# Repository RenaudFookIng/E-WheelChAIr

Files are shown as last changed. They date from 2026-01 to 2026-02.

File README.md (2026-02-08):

# E-WheelChAIr
**Smart Embedded System for Electric Wheelchairs**




---

## Description
E-WheelChAIr is an open-source project designed to enhance autonomy and accessibility for electric wheelchairs. It integrates:
- A **ROS2-based architecture** for real-time control and sensor fusion.
- **3D-printed mechanical parts** (sensor mounts, joystick adapters).
- **Modular design** for easy customization and collaboration with partners like Sorbonne University.

---

## 📸 Visual Overview

### Wheelchair Views

<div align="center">
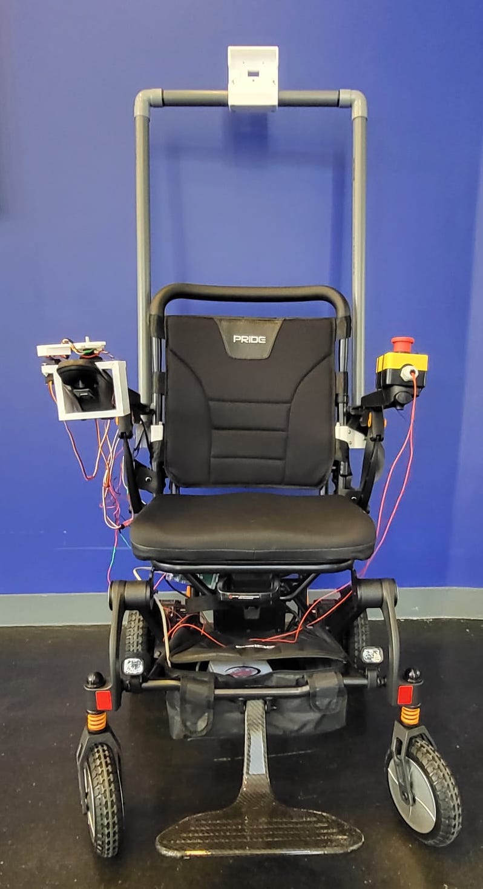
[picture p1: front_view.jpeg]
Front View
  
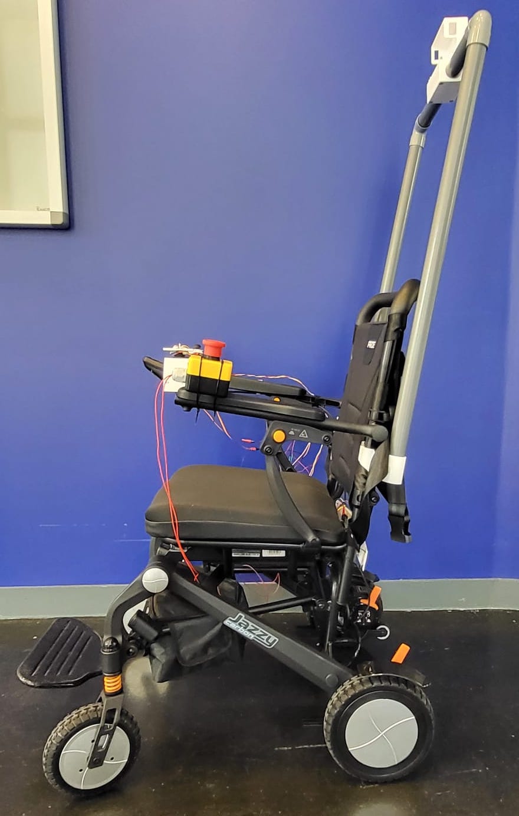
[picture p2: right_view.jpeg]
Right View
  
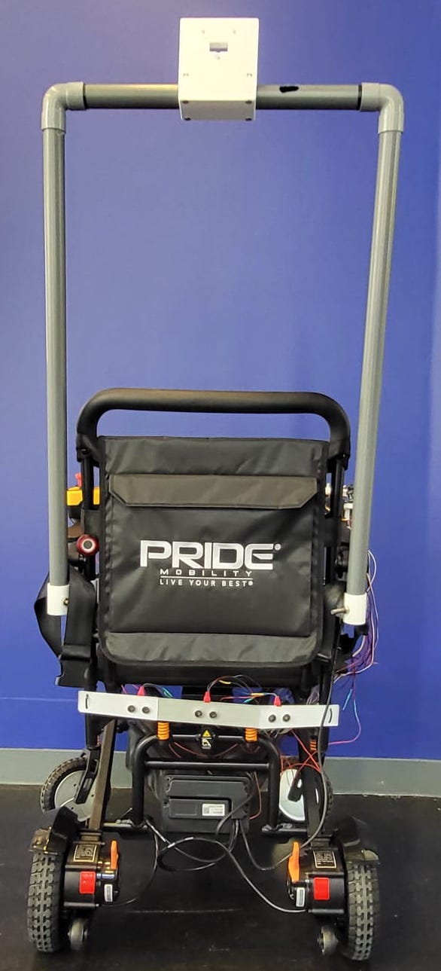
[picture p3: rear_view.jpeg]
Rear View
  
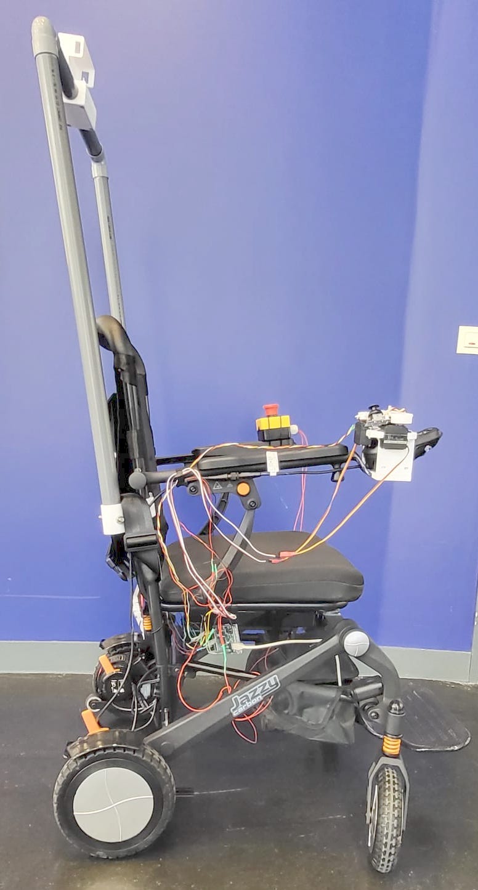
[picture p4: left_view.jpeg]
Left View
  
</div>

---

## Project Structure

**Note:** All ROS launch files are centralized in the `e_wheelchair_launch` package for easier management.

```
E-WheelChAIr/
├── hardware
│   ├── 3d_models
│   │   ├── BackRest_Fixation/
│   │   │   ├── Fixation_BackRest.iges
│   │   │   ├── Fixation_backrest_part1.stl
│   │   │   └── Fixation_backrest_part2.stl
│   │   ├── Camera_Module/
│   │   │   ├── Camera_module.iges
│   │   │   ├── Fixation_camera.stl
│   │   │   ├── Fixation_camera_up.stl
│   │   │   └── Support_camera.stl
│   │   ├── ServoControl_Joystick/
│   │   │   ├── BasePart.stl
│   │   │   ├── FourchetteAxeX.stl
│   │   │   ├── FourchetteAxeY.stl
│   │   │   ├── Servo_controller_Joystick.iges
│   │   │   ├── Support_servo_joystick.stl
│   │   │   └── Visuel_Joystick_servomoteur_support.png
│   │   └── Ultrasonic_Module/
│   │
│   ├── arduino/
│   │   ├── ewheelchair_controller/
│   │   │   ├── ewheelchair_controller.ino
│   │   │   └── lecture_arduino.py
│   │   ├── ARDUINO_GUIDE.md
│   │   ├── FILES_SUMMARY.md
│   │   ├── README.md
│   │   └── test_arduino.py
│   │
│   ├── Image_processing/
│   │   ├── cmd.txt
│   │   ├── ROS.txt
│   │   ├── vision_config_gpu.py
│   │   ├── vision_config_mac.py
│   │   ├── vision_system_gpu.py
│   │   ├── vision_system_mac.py
│   │   ├── yolo11n.pt
│   │   └── yolov8n.pt
│   │
│   └── Right_View.jpeg
│
├── resources
│   ├── docs
│   └── utils
|
├── src
|   ├── arduino_bridge/
|   │   ├── arduino_bridge
|   │   │   ├── __init__.py
|   │   │   └── arduino_bridge_node.py
|   │   ├── resource
|   │   │   └── arduino_bridge
|   │   ├── test
|   │   │   ├── test_copyright.py
|   │   │   ├── test_flake8.py
|   │   │   └── test_pep257.py
|   │   ├── package.xml
|   │   ├── setup.cfg
|   │   └── setup.py
|   ├── custom_msgs/
|   │   ├── msg/
|   │   │   ├── EmergencyData.msg
|   │   │   ├── Joystick.msg
|   │   │   ├── ObstacleDetection.msg
|   │   │   ├── ServoCommand.msg
|   │   │   ├── UltrasonicArray.msg
|   │   │   ├── VisionObstacle.msg
|   │   │   └── WyesIntent.msg
|   │   ├── CMakeLists.txt
|   │   ├── package.xml
|   │   └── setup.py
|   ├── e_wheelchair_launch/
|   │   ├── e_wheelchair_launch
|   │   │   ├── __init__.py
|   │   │   └── launch/
|   │   ├── resource/
|   │   │   └── e_wheelchair_launch
|   │   ├── package.xml
|   │   ├── setup.cfg
|   │   └── setup.py
|   ├── master_node/
|   │   ├── config/
|   │   │   ├── master_config.yaml
|   │   │   └── servo_config.yaml
|   │   ├── master_node/
|   │   │   ├── __init__.py
|   │   │   ├── master_node.py
|   │   │   └── master_node_bis.py
|   │   ├── package.xml
|   │   ├── setup.cfg
|   │   └── setup.py
|   ├── pc_vision_bridge/
|   │   ├── pc_vision_bridge
|   │   │   ├── __init__.py
|   │   │   └── pc_vision_bridge_node.py
|   │   ├── resource
|   │   │   └── pc_vision_bridge
|   │   ├── test
|   │   │   ├── test_copyright.py
|   │   │   ├── test_flake8.py
|   │   │   └── test_pep257.py
|   │   ├── package.xml
|   │   ├── setup.cfg
|   │   └── setup.py
|   └── wyes_teleop/
|       ├── resource
|       │   └── wyes_teleop
|       ├── test
|       │   ├── test_copyright.py
|       │   ├── test_flake8.py
|       │   └── test_pep257.py
|       ├── wyes_teleop
|       │   ├── __init__.py
|       │   └── wyes_teleop_node.py
|       ├── package.xml
|       ├── setup.cfg
|       └── setup.py
|
├── .gitignore
├── CABLAGE_SCHEMA.md
├── E-WheelChAIr.mp4
├── LICENSE
├── parametrage_raspberry_hotspot.txt
├── README.md
├── TESTING_GUIDE.md
└── yolov8n.pt
```

---

## Prerequisites

### Hardware
- Electric wheelchair with servo-controlled joystick (using Miuzei MZ996 servos).
- Sensors: Intel Realsense (depth camera), HC-SR04 (ultrasonic), Arduino (I/O interface).
- Joystick or alternative control input device.

### Software
- ROS2 Jazzy.
- colcon (build tool for ROS2).
- OnShape (for 3D modeling).
- Git LFS (for versioning large 3D files).
- Python 3.9+ with pyserial and pyyaml packages.

---

## Installation and Setup On your computer

### 1. Clone the Repository
```bash
git clone https://github.com/RenaudFookIng/E-WheelChAIr.git
cd E-WheelChAIr
```

### 2. Build the ROS Workspace
```bash
colcon build --symlink-install
source install/setup.bash
```

### 3. Launch the System
```bash
ros2 launch e_wheelchair_launch ewheelchair_all.launch.py
```
## Installation and Setup On your Raspberry PI

### 1. Cloner le dépôt en mode "sparse-checkout"
```bash
git clone --filter=blob:none --no-checkout https://github.com/RenaudFookIng/E-WheelChAIr.git
cd E-WheelChAIr
```
### 2. Active le mode sparse-checkout et exclut le dossier 'hardware'
```bash
git sparse-checkout init --cone
git sparse-checkout set --no-cone /* !/hardware/
```
### 3. Extrait les fichiers (sauf 'hardware')
```bash
git checkout main
```

## Build the ROS Workspace
```bash
colcon build --symlink-install
source install/setup.bash
```

---

## ROS Launch Files Centralization

All ROS launch files have been centralized in the `e_wheelchair_launch` package to provide:

- **Simplified Management**: Single location for all launch configurations
- **Easier Maintenance**: No duplication across packages
- **Consistent Structure**: Uniform approach to system launching
- **Better Organization**: Clear separation between nodes and launch configurations

### Available Launch Files

| Launch File | Description | Components Launched |
|---|---|---|
| `ewheelchair_all.launch.py` | Complete system with all sensors and processing | 6 nodes |
| `ewheelchair_joystick_servo.launch.py` | Control servo with joystick and Ultrasonic sensor | 2 node |
| `ewheelchair_arduino_vision.launch.py` | Control servo with joystick and Ultrasonic sensor and Wide-angle camera processing | 3 node |
| `ewheelchair_wyes_teleop.launch.py` | Control servo with joystick, Ultrasonic sensor and Wyes Glasses | 3 node |

## ROS Packages

| Package | Description |
|---|---|
| `arduino_bridge` | Receives data from Arduino sensors |
| `custom_msgs` | Custom ROS message definitions |
| `e_wheelchair_launch`  | Launch files for the complete system |
| `master_node` | Main control node for servo-controlled joystick |
| `pc_vision_bridge` | Bridge between PC vision system and ROS |
| `wyes_teleop` | Keyboard-based teleoperation interface |

---
Pour se connecter au Hotspot WiFi :
- Nom du Hotspot : E-Wheelchair
- Mot de passe : REDACTED_WIFI_PASSWORD

Pour se connecter à la plateforme :
Nom de la plateforme : ewheelchair2
```bash
ssh ewheelchair2@192.168.4.1
```
mdp : REDACTED_SSH_PASSWORD

---

## 3D Models
- **Location**: [`3d_models/`](3d_models/)
- **Formats**: STL and STEP files for 3D printing and simulation.
- **Tools**: Designed in OnShape.
- **Note**: Use `git lfs pull` after cloning to retrieve 3D files.

---

## Recent Changes

### Version 0.2.0 (Current)
- **Major Architecture Change**: Replaced Sabertooth motor controller with Miuzei MZ996 servo-based joystick control
- **New Package**: `arduino_bridge` for Arduino-based servo management
- **Updated**: `master_node` now publishes joystick commands instead of motor commands
- **Updated**: `visualization` package removed motor speed plotting
- **Improved**: Safety features with neutral position on emergency stop

### Version 0.1.0
- Initial release with Sabertooth motor controller
- Basic sensor integration (ultrasonic, camera)
- ROS2 Jazzy compatibility

## Collaboration
- **University of Milan**: Partner for accessibility validation.
- **Contributions**: Pull requests and issues are welcome!
- **License**: Apache 2.0 (see [LICENSE](LICENSE)).

---

## Contact
- **Maintainer**: Renaud JANET ([@RenaudFookIng](https://github.com/RenaudFookIng))
- **Support**: Open an [issue](https://github.com/RenaudFookIng/E-WheelChAIr/issues) for questions or suggestions.

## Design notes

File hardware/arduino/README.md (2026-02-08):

# E-WheelChAIr Arduino Controller

This directory contains the Arduino firmware for the E-WheelChAIr project.

## 📁 Files

- `ewheelchair_controller/ewheelchair_controller.ino` - Main Arduino sketch for Arduino Mega 2560
- `test_arduino.py` - Python test script for verifying Arduino functionality

## 🎯 Hardware Requirements

- **Arduino Mega 2560** (required for sufficient pins)
- **Joystick PS2** - Analog joystick for user input
- **2x MZ996R Servos** - For wheelchair joystick manipulation
- **4x HC-SR04 Ultrasonic Sensors** - For obstacle detection
- **6V Power Supply** - For servos (NOT from Arduino!)

## 🔌 Pin Configuration

### Analog Inputs
- **A0**: Joystick X-axis
- **A1**: Joystick Y-axis

### Digital Outputs
- **D9**: Servo Y (Vertical - Forward/Backward)
- **D10**: Servo X (Horizontal - Left/Right)
- **30**: Ultrasonic 1 Trigger (Rear Right sensor)
- **31**: Ultrasonic 1 Echo (Rear Right sensor)
- **32**: Ultrasonic 2 Trigger (Rear Central sensor)
- **33**: Ultrasonic 2 Echo (Rear Central sensor)
- **34**: Ultrasonic 3 Trigger (Rear Left sensor)
- **35**: Ultrasonic 3 Echo (Rear Left sensor)

### Power
- **5V**: Power for ultrasonic sensors and joystick
- **GND**: Common ground for all components

## 📦 Installation

### 1. Install Arduino IDE

```bash
# For Ubuntu/Debian
sudo apt install arduino

# Or download from https://www.arduino.cc/en/software
```

### 2. Install Required Libraries

The sketch uses the standard `Servo.h` library which comes with Arduino IDE.

### 3. Upload the Code

1. Open `ewheelchair_controller/ewheelchair_controller.ino` in Arduino IDE
2. Select board: **Arduino Mega 2560**
3. Select port: Check with `ls /dev/ttyACM*` on Linux or COM port on Windows
4. Click **Upload** (→)

## 🚀 Usage

### Serial Communication Protocol

The Arduino communicates at **115200 baud** using the following protocol:

#### Commands (ROS2 → Arduino)

- **`SERVO,X,Y`**: Set servo positions
  - `X`: X-axis angle (77-107°, neutral=92°)
  - `Y`: Y-axis angle (70-100°, neutral=85°)
  - Example: `SERVO,90,85` (neutral position)

- **`NEUTRAL`**: Return servos to neutral position
  - Response: `NEUTRAL_OK`

- **`STATUS`**: Request current status
  - Response: `STATUS,X,Y,neutralX,neutralY,amplitude`

#### Data (Arduino → ROS2)

- **`JOYSTICK,X,Y`**: Joystick position data
  - `X`: X-axis angle (0-180°)
  - `Y`: Y-axis angle (0-180°)
  - Sent every 50ms (20Hz)

- **`ULTRASONIC,d1,d2,d3,d4`**: Ultrasonic sensor distances
  - `d1`: Front sensor distance (meters)
  - `d2`: Rear sensor distance (meters)
  - `d3`: Left sensor distance (meters)
  - `d4`: Right sensor distance (meters)
  - Sent every 50ms (20Hz)

- **`SERVO_OK,X,Y`**: Confirmation of servo movement
  - `X`: Actual X position set
  - `Y`: Actual Y position set

- **`ERROR,message`**: Error messages

## ⚙️ Configuration

### Servo Parameters

Edit these values in the sketch if needed:

```cpp
int neutralX = 92;    // Neutral position for X servo
int neutralY = 85;    // Neutral position for Y servo
int amplitude = 15;   // ±15° amplitude limit
```

### Safety Features

- **Timeout**: Servos automatically return to neutral after 1 second without commands
- **Amplitude Limit**: Strict ±15° limit to prevent over-extension
- **Distance Clamping**: Ultrasonic readings constrained to 2cm-4m range

## 🧪 Testing

### Run the Test Script

```bash
python3 test_arduino.py
```

### Manual Testing

1. **Joystick Test**: Move joystick and check serial output
2. **Servo Test**: Send `SERVO,92,85` command
3. **Ultrasonic Test**: Place hand in front of sensors
4. **Safety Test**: Disconnect serial and verify timeout

## 🔄 ROS2 Integration

The Arduino connects to the ROS2 system via:

```
Arduino Mega (USB) → Raspberry Pi (/dev/ttyACM0)
```

The ROS2 `arduino_bridge_node` sends commands and receives sensor data.

## ⚠️ Safety Instructions

1. **Always test servos before connecting to wheelchair**
2. **Use external 6V power for servos** (NOT from Arduino)
3. **Ensure common ground between all components**
4. **Keep emergency stop accessible**
5. **Verify ±15° amplitude limits before use**

## 📊 Troubleshooting

### Common Issues

**Problem**: Servos don't move
- Check 8V power connection
- Verify GND is common
- Test with simple Arduino servo example

**Problem**: Ultrasonic always shows 4.0m
- Check Trig/Echo wiring
- Verify 5V power connection
- Test with hand at 20cm distance

**Problem**: No serial communication
- Check USB cable connection
- Verify correct port selection
- Ensure baud rate is 115200
- Close Arduino Serial Monitor before running ROS2

**Problem**: Joystick not responding
- Check A0/A1 connections
- Verify 5V power to joystick
- Test with Arduino analog read example

## 📚 References

- [Arduino Servo Library](https://www.arduino.cc/en/Reference/Servo)
- [HC-SR04 Ultrasonic Sensor](https://www.electronicwings.com/sensors-modules/hc-sr04-ultrasonic-sensor)
- [PS2 Joystick Guide](https://www.instructables.com/How-to-Use-a-Joystick-With-Arduino/)

## 🎓 Notes

- The Y-axis neutral position is **85°** (not 90°) to match wheelchair mechanics
- The X-axis neutral position is **92°** (not 90°) to match wheelchair mechanics
- Servo amplitude is **strictly limited to ±15°** for safety
- All ultrasonic sensors are read sequentially to avoid interference
- Serial communication uses newline (`\n`) as command terminator

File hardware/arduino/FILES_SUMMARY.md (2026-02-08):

# 📁 E-WheelChAIr Arduino Files Summary

## 📂 Directory Structure

```
hardware/arduino/
├── ewheelchair_controller/
│   └── ewheelchair_controller.ino          # Main Arduino sketch (fully commented)
├── test_arduino.py                          # Python test script
├── README.md                                # Basic documentation
├── ARDUINO_GUIDE.md                         # Complete technical guide
├── FILES_SUMMARY.md                         # This file
└── (other documentation files)
```

## 📄 File Descriptions

### 1. `ewheelchair_controller/ewheelchair_controller.ino`
**Purpose**: Main Arduino sketch for E-WheelChAIr hardware control (fully documented)
**Size**: 11KB
**Language**: C++ (Arduino)
**Target**: Arduino Mega 2560

**Key Features:**
- Controls 2 servos with ±15° safety limits
- Reads PS2 joystick input
- Manages 3 ultrasonic sensors
- Serial communication at 115200 baud
- Safety timeout (1 second)
- Emergency stop function
- **Fully documented with line-by-line comments**

**Functions:**
- `setup()` - Initialization
- `loop()` - Main control loop
- `processSerialCommand()` - Command processing
- `sendJoystickData()` - Joystick data transmission
- `sendUltrasonicData()` - Ultrasonic data transmission
- `readUltrasonicDistance()` - Single sensor reading
- `moveToNeutral()` - Safety function
- `emergencyStop()` - Emergency function

**Documentation Includes:**
- Hardware requirements
- Pin definitions with explanations
- Servo configuration details
- Serial protocol specification
- Safety feature descriptions
- Testing procedures

### 3. `test_arduino.py`
**Purpose**: Python script for testing Arduino functionality
**Size**: 4KB
**Language**: Python 3
**Dependencies**: pyserial

**Key Features:**
- Automatic Arduino port detection
- Comprehensive test suite
- Serial communication validation
- Error handling and reporting
- Cross-platform support (Windows/Linux/macOS)

**Tests Performed:**
1. Port detection and connection
2. STATUS command validation
3. NEUTRAL command testing
4. SERVO command execution
5. Sensor data verification
6. Error response handling

**Usage:**
```bash
python3 test_arduino.py
```

### 4. `README.md`
**Purpose**: Basic documentation and quick start guide
**Size**: 5.4KB
**Format**: Markdown

**Sections:**
- Files overview
- Hardware requirements
- Pin configuration table
- Installation instructions
- Usage guide
- Serial protocol specification
- Safety instructions
- Troubleshooting guide
- References and links

**Key Information:**
- Hardware requirements list
- Pin mapping diagram
- Arduino IDE setup
- Upload instructions
- Serial protocol examples
- Common issues and solutions

### 5. `ARDUINO_GUIDE.md`
**Purpose**: Complete technical reference and user guide
**Size**: 11.8KB
**Format**: Markdown

**Sections:**
- Overview and system architecture
- Hardware components specification
- Detailed pin mapping
- Servo configuration guide
- Serial communication protocol
- Safety features explanation
- Data flow diagrams
- Testing procedures
- Wiring checklist
- Power requirements
- Troubleshooting guide
- Key concepts and theory
- Reference specifications
- Maintenance tips
- Glossary of terms
- Quick reference guide
- ROS2 integration
- Performance metrics
- Best practices

**Key Information:**
- Why Arduino Mega is required
- X-axis neutral position explanation (85°)
- Complete safety feature documentation
- Step-by-step testing procedures
- Power budget calculations
- Component specifications
- Integration with ROS2 nodes
- Maintenance schedule

## 📊 File Statistics

| File | Size | Lines | Language | Purpose |
|---|---|---|---|---|
| `ewheelchair_controller.ino` | 11KB | 420 | C++ | Main sketch (fully documented) |
| `test_arduino.py` | 4KB | 150 | Python | Test script |
| `README.md` | 5.4KB | 200 | Markdown | Quick start |
| `ARDUINO_GUIDE.md` | 11.8KB | 450 | Markdown | Complete guide |
| `FILES_SUMMARY.md` | 2KB | 80 | Markdown | This summary |

**Total**: ~40KB, ~1,500 lines of code and documentation

## 🔧 Development Tools

### Required Software
- **Arduino IDE** 1.8+ or 2.0+
- **Python** 3.6+
- **pyserial** library
- **Git** for version control

### Installation Commands
```bash
# Install Arduino IDE (Ubuntu/Debian)
sudo apt install arduino

# Install Python dependencies
pip3 install pyserial

# Clone repository
git clone https://github.com/your-repo/E-WheelChAIr.git
```

## 🚀 Getting Started

### 1. Upload Arduino Sketch
```bash
# Open Arduino IDE
arduino

# Select board: Arduino Mega 2560
# Select port: /dev/ttyACM0 or COMx
# Open ewheelchair_controller.ino
# Click Upload (→)
```

### 2. Run Test Script
```bash
python3 test_arduino.py
```

### 3. Connect to ROS2
```bash
# The Arduino will automatically connect to ROS2 via
# /dev/ttyACM1 at 115200 baud
```

## 📚 Documentation Hierarchy

```
Quick Start → README.md
            ↓
Detailed Guide → ARDUINO_GUIDE.md
            ↓
Code Reference → Commented sketch
            ↓
Testing → test_arduino.py
```

## 🎯 Key Features Summary

### Safety
- ±15° amplitude limiting
- 1-second timeout protection
- Emergency stop function
- Distance clamping (2cm-4m)

### Performance
- 20Hz update rate
- Low latency (<20ms)
- Efficient resource usage
- Reliable communication

### Documentation
- Complete pin mapping
- Detailed explanations
- Troubleshooting guides
- Best practices

### Testing
- Automatic port detection
- Comprehensive test suite
- Error handling
- Validation procedures

## 🔄 Version Control

### Git Repository Structure
```
hardware/arduino/
├── ewheelchair_controller/
│   └── ewheelchair_controller.ino
├── test_arduino.py
├── README.md
├── ARDUINO_GUIDE.md
└── FILES_SUMMARY.md
```

### Commit Message Template
```
[ARDUINO] Add complete hardware controller

- Main Arduino sketch for Mega 2560
- Fully documented version for understanding
- Python test script with automatic detection
- Comprehensive README and guide
- Safety features and testing procedures

Fixes #issue_number
```

## 📖 Usage Recommendations

### For Developers
1. Start with `README.md` for quick setup
2. Use the fully documented sketch for code understanding
3. Run test script for validation
4. Refer to `ARDUINO_GUIDE.md` for troubleshooting

### For Users
1. Upload main sketch to Arduino
2. Follow wiring diagram in `CABLAGE_SCHEMA.md`
3. Run test script to verify functionality
4. Connect to ROS2 system

### For Maintainers
1. Update documentation when making changes
2. Test all modifications with test script
3. Verify safety features remain intact
4. Document any wiring or configuration changes

## 🎓 Learning Resources

### Arduino
- [Arduino Official Guide](https://www.arduino.cc/en/Guide)
- [Servo Library Reference](https://www.arduino.cc/en/Reference/Servo)
- [Serial Communication](https://www.arduino.cc/reference/en/language/functions/communication/serial/)

### Sensors
- [HC-SR04 Ultrasonic Guide](https://www.electronicwings.com/sensors-modules/hc-sr04-ultrasonic-sensor)
- [PS2 Joystick Tutorial](https://www.instructables.com/How-to-Use-a-Joystick-With-Arduino/)

### ROS2
- [ROS2 Documentation](https://docs.ros.org/en/jazzy/)
- [Serial Communication in ROS2](https://docs.ros.org/en/jazzy/Tutorials/Beginner-CLI-Tools/Introducing-Turtlesim/Introducing-Turtlesim.html)

## 📊 File Relationships

```
Main Sketch → Test Script → Documentation
    ↑               ↓
Hardware ← ROS2 Integration
```

## 🔧 Maintenance Checklist

### Regular Updates
- [ ] Update documentation when hardware changes
- [ ] Test all examples after modifications
- [ ] Verify safety features remain functional
- [ ] Check pin mappings are current

### Version Updates
- [ ] Increment version numbers
- [ ] Update changelog
- [ ] Test backward compatibility
- [ ] Document breaking changes

## 📖 Conclusion

This collection of files provides a **complete hardware control system** for the E-WheelChAIr project:

1. **Functional Code**: Ready-to-use Arduino sketch
2. **Comprehensive Documentation**: From quick start to deep technical reference
3. **Testing Framework**: Automated validation and verification
4. **Safety Features**: Built-in protection mechanisms
5. **Integration Ready**: Designed to work with ROS2 system

The documentation follows a **progressive disclosure** approach:
- Start with simple guides
- Provide detailed references when needed
- Include practical examples
- Offer troubleshooting assistance

This structure ensures that both **beginners** and **experienced developers** can work effectively with the hardware controller.

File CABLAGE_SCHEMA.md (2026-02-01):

# Schéma de Câblage - E-WheelChAIr (1 Arduino Mega)

## 📐 Vue d'Ensemble

```
+---------------------+
|   Arduino Mega      |
|                     |
|  A0 ──── Joystick X |
|  A1 ──── Joystick Y |
|  D9 ──── Servo Y    |
|  D10 ─── Servo X    |
|  D2 ──── US4 Trig   |
|  D3 ──── US3 Echo   |
|  D4 ──── US2 Echo   |
|  D5 ──── US1 Trig   |
|  D6 ──── US1 Echo   |
|  D7 ──── US2 Trig   |
|  D8 ──── US3 Trig   |
|  D13 ─── US4 Echo   |
|  GND ─── GND Commun |
|  5V ──── 5V Capteurs|
+---------------------+
       │ USB
       ▼
+---------------------+
|   Raspberry Pi      |
|   (ROS2)            |
+---------------------+
```

## 🔌 Câblage Détailé

### 1. Joystick PS2

```
[Joystick PS2]
   │
   ├── Rouge  → +5V (Arduino)
   ├── Noir   → GND (Arduino)
   ├── Jaune  → A0 (X-axis)
   ├── Vert   → A1 (Y-axis)
   └── Blanc  → (Non utilisé)
```

**Vérification** :
- Mesurer la tension entre Rouge et Noir : doit être ~5V
- Vérifier que X et Y varient entre 0-1023 dans le moniteur série

### 2. Servomoteurs MG996R

```
[Servo X - Gauche/Droite]
   │
   ├── Rouge  → +6V (Alim externe)
   ├── Marron → GND (Alim externe)
   └── Orange → D10 (Arduino)

[Servo Y - Avant/Arrière]
   │
   ├── Rouge  → +6V (Alim externe)
   ├── Marron → GND (Alim externe)
   └── Orange → D9 (Arduino)
```

**IMPORTANT** :
- GND **commun** entre alimentation et Arduino
- Courant max : 2A par servo sous charge

### 3. Capteurs Ultrasons (HC-SR04)

```
[Ultrason 1 - Arrière Droite]
   │
   ├── VCC   → +5V (Arduino)
   ├── Trig  → 30 (Arduino)
   ├── Echo  → 31 (Arduino)
   └── GND   → GND (Arduino)

[Ultrason 2 - Arrière Central]
   │
   ├── VCC   → +5V (Arduino)
   ├── Trig  → 32 (Arduino)
   ├── Echo  → 33 (Arduino)
   └── GND   → GND (Arduino)

[Ultrason 3 - Arrière Gauche]
   │
   ├── VCC   → +5V (Arduino)
   ├── Trig  → 34 (Arduino)
   ├── Echo  → 35 (Arduino)
   └── GND   → GND (Arduino)

```

**Positionnement recommandé** :
- Arrière Droite : Capteur 1
- Arriere Central : Capteur 2
- Arriere Gauche : Capteur 3

### 4. Alimentation

```
[Alimentation 5V Raspberry Pi]
   │
   └── USB  →  Arduino Mega (Port série)
```

### 5. Raspberry Pi

```
[Raspberry Pi]
   │
   └── USB → Arduino Mega (Port série)
```

**Configuration** :
- Port série : `/dev/ttyACM0` (vérifier avec `ls /dev/ttyACM*`)
- Baudrate : 115200
- Permissions : `sudo chmod a+rw /dev/ttyACM0`

## 📊 Tableau de Branchement

| Composant | Broche Arduino | Broche Composant | Couleur Fil |
|---|---|---|---|
| Joystick X | A0 | X | Jaune |
| Joystick Y | A1 | Y | Vert |
| Servo X (G/D) | D10 | Signal | Orange |
| Servo Y (A/A) | D9 | Signal | Orange |
| Ultrason 1 Trig | 30 | Trig | Marron |
| Ultrason 1 Echo | 31 | Echo | Bleu |
| Ultrason 2 Trig | 32 | Trig | Marron |
| Ultrason 2 Echo | 33 | Echo | Bleu |
| Ultrason 3 Trig | 34 | Trig | Marron |
| Ultrason 3 Echo | 35 | Echo | Bleu |
| Alim 5V | 5V | VCC (tous) | Rouge |
| GND Commun | GND | GND (tous) | Noir |

## ⚠️ Vérifications de Sécurité

### Avant Premier Allumage

1. **Vérifier les tensions** :
   ```bash
   # Mesurer entre GND et +5V Arduino
   # Doit être : 4.8V - 5.2V
   ```

2. **Vérifier les connexions** :
   - Pas de court-circuit
   - Tous les GND connectés ensemble
   - Alimentation servos séparée

3. **Tester les servos** :
   ```bash
   # Sans rien brancher au fauteuil
   ros2 topic pub /servo_commands custom_msgs/msg/ServoCommand "{x_normalized: 0.5, y_normalized: 0.0}"
   ```

### Après Branchement

1. **Vérifier les amplitudes** :
   - Max +15° : `ros2 topic pub /servo_commands ... "{x_normalized: 1.0, y_normalized: 1.0}"`
   - Max -15° : `ros2 topic pub /servo_commands ... "{x_normalized: -1.0, y_normalized: -1.0}"`

2. **Tester les ultrasons** :
   ```bash
   ros2 topic echo /ultrasonic_data
   # Doit afficher 3 valeurs entre 0.02 et 4.0
   ```

3. **Vérifier le joystick** :
   ```bash
   ros2 topic echo /joystick_data
   # Doit varier entre -1.0 et 1.0
   ```

## 📱 Dépannage Visuel

### Problème : Servos ne bougent pas

**Causes** :
- ❌ GND non commun
- ❌ Broches servos inversées

**Solution** :
1. Vérifier continuité GND
2. Tester avec exemple Arduino simple

### Problème : Ultrasons toujours à 4.0m

**Causes** :
- ❌ Branchement Trig/Echo inversé
- ❌ Objet trop proche (<2cm)
- ❌ Objet trop éloigné (>4m)

**Solution** :
1. Vérifier branchements
2. Tester avec main à 20cm
3. Vérifier dans moniteur série

### Problème : Joystick non détecté

**Causes** :
- ❌ A0/A1 non branchés
- ❌ Joystick défectueux
- ❌ Alimentation manquante

**Solution** :
1. Mesurer tension joystick
2. Tester avec autre joystick
3. Vérifier valeurs dans moniteur série

## 🎯 Checklist Final

- [ ] Branchements vérifiés (2x)
- [ ] GND commun à tous
- [ ] Code Arduino téléversé
- [ ] ROS2 compilé
- [ ] Ports série configurés
- [ ] Tests unitaires passés
- [ ] Sécurité mécanique OK

## 📚 Schéma Visuel Simplifié

```
+-----------+       +-------------------+       +-----------+
| Joystick  |       |   Arduino Mega    |       | Servos    |
|  PS2      |       |                   |       | MG996R   |
+-----+-----+       +--------+----------+       +-----+-----+
      │                  │ USB              │             │
      │ A0,A1            │                  │ D9,D10      │
      │                  +--------+----------+             │
      │                           │                     │
      └───────────────────┼─────────────────┘
                          │
                          ▼
                    +-------------+
                    | Raspberry Pi|
                    |   ROS2      |
                    +-------------+
```

---

**⚠️ Sécurité** : Toujours tester les servos **avant** connexion au fauteuil.
**🔧 Outils** : Multimètre, tournevis, pince à dénuder.
**✅ Validation** : Vérifier chaque étape avant de passer à la suivante.

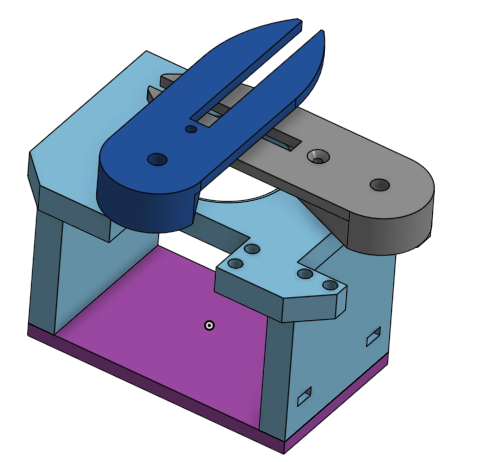
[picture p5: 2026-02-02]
hardware/3d_models/ServoControl_Joystick/Visuel_Joystick_servomoteur_support.png

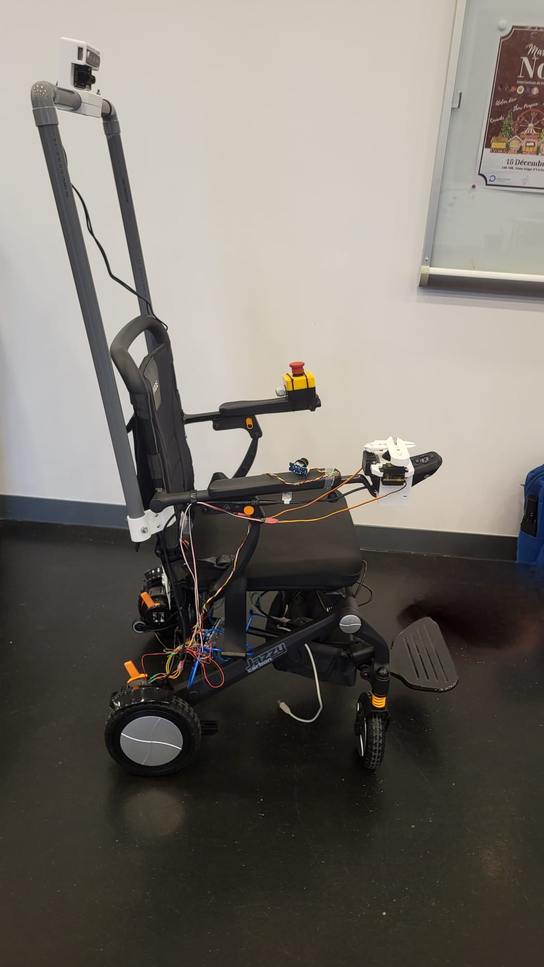
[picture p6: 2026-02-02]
hardware/Right_View.jpeg

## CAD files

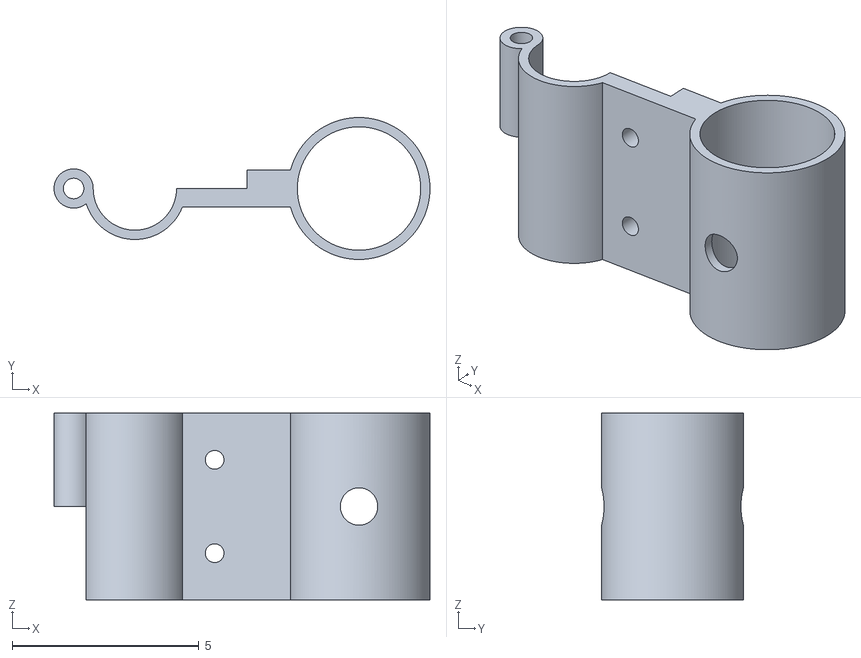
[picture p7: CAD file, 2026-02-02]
hardware/3d_models/BackRest_Fixation/Fixation_backrest_part1.stl
10.1 x 3.80 x 5.00

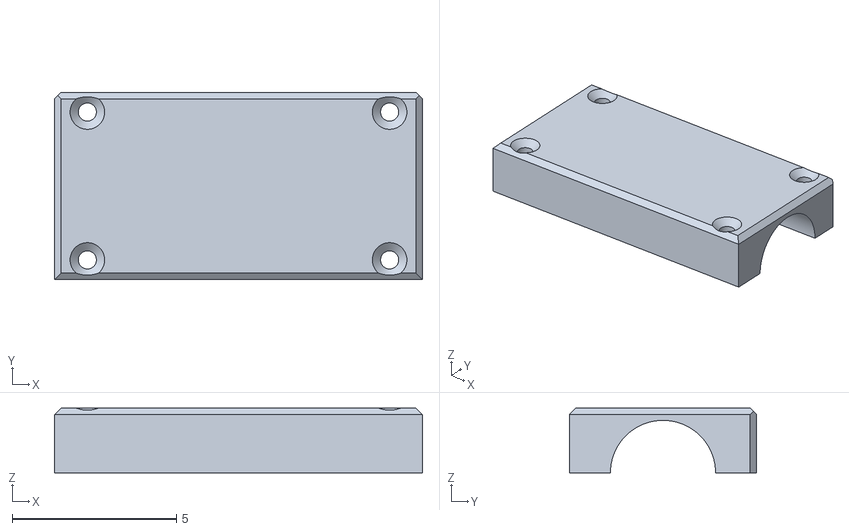
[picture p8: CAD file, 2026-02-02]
hardware/3d_models/Camera_Module/Fixation_camera_up.stl
11.2 x 5.70 x 1.98

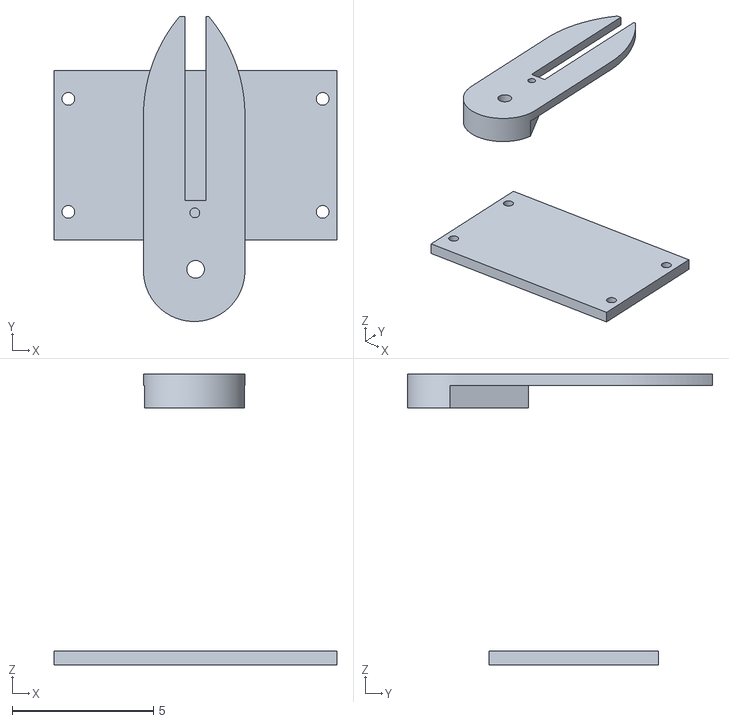
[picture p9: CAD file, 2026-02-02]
hardware/3d_models/ServoControl_Joystick/BasePart.stl
10.0 x 10.8 x 10.3

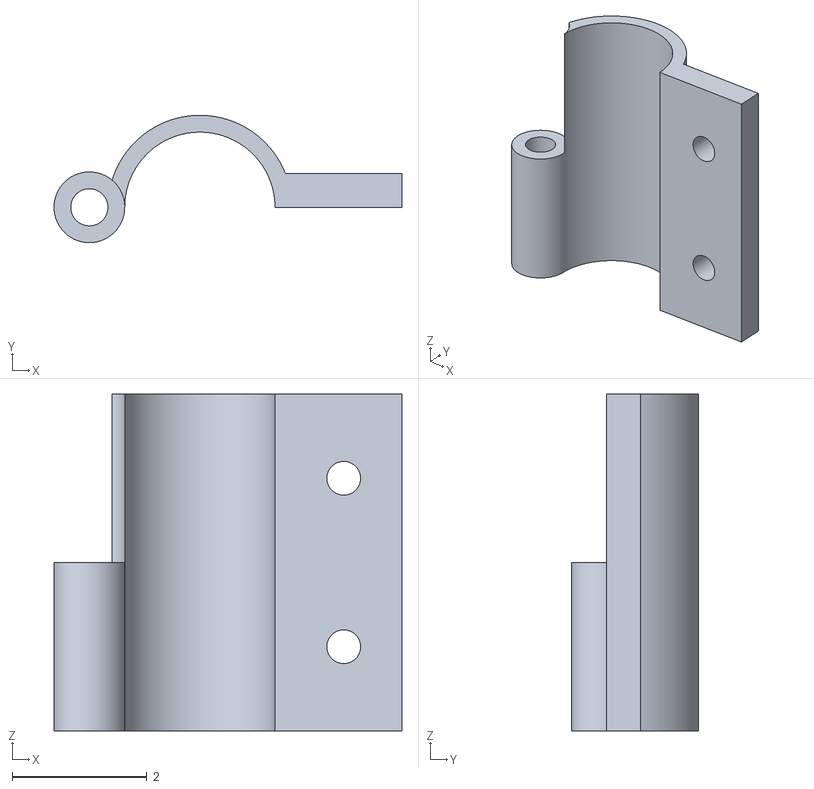
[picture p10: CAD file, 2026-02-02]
hardware/3d_models/BackRest_Fixation/Fixation_backrest_part2.stl
5.16 x 1.89 x 5.00

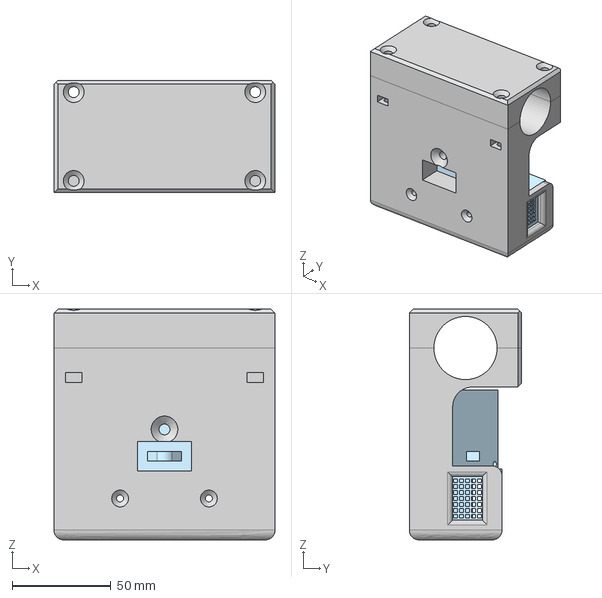
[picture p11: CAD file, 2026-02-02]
hardware/3d_models/Camera_Module/Camera_module.iges
112.0 x 57.0 x 117.0 mm

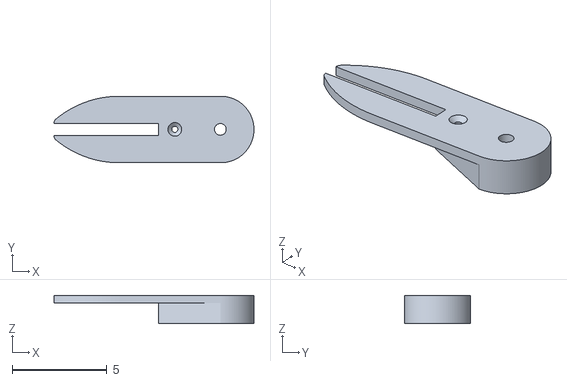
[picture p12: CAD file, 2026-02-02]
hardware/3d_models/ServoControl_Joystick/FourchetteAxeY.stl
10.5 x 3.50 x 1.50

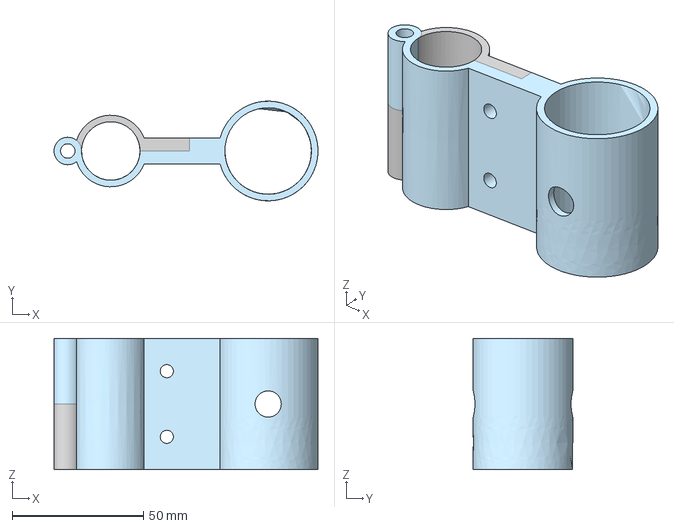
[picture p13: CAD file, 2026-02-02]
hardware/3d_models/BackRest_Fixation/Fixation_BackRest.iges
100.6 x 38.0 x 50.0 mm

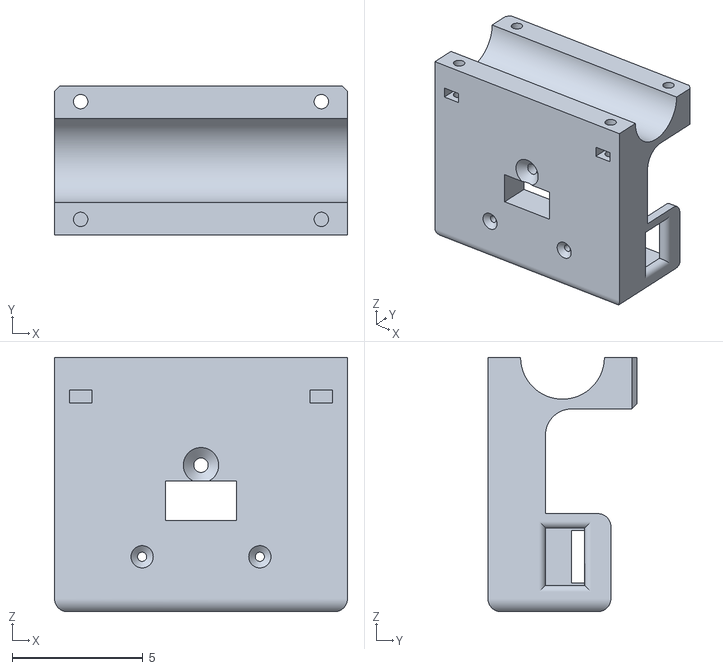
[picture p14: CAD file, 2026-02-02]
hardware/3d_models/Camera_Module/Fixation_camera.stl
11.2 x 5.70 x 9.72

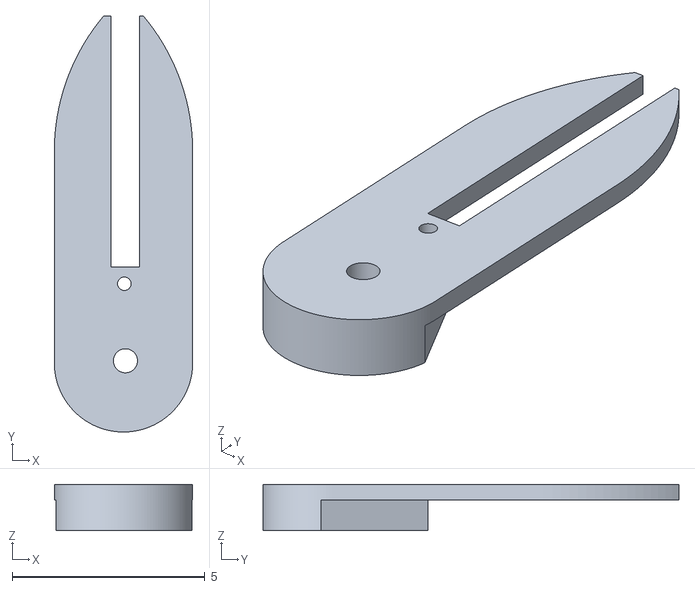
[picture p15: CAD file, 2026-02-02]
hardware/3d_models/ServoControl_Joystick/FourchetteAxeX.stl
3.59 x 10.8 x 1.20

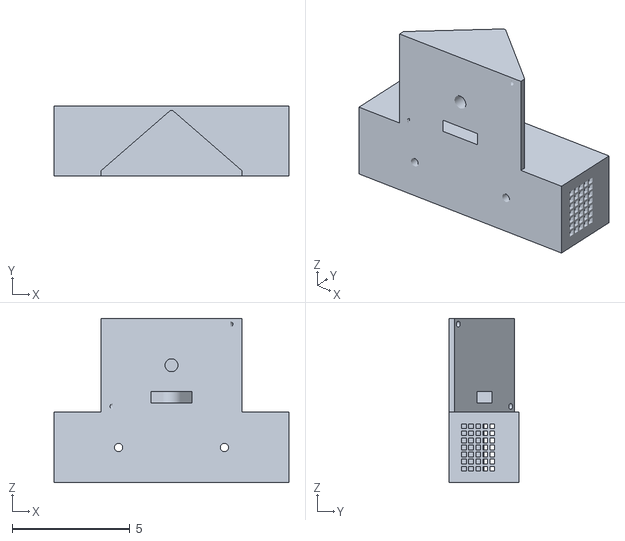
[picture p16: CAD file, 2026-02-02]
hardware/3d_models/Camera_Module/Support_camera.stl
10.0 x 3.00 x 7.00

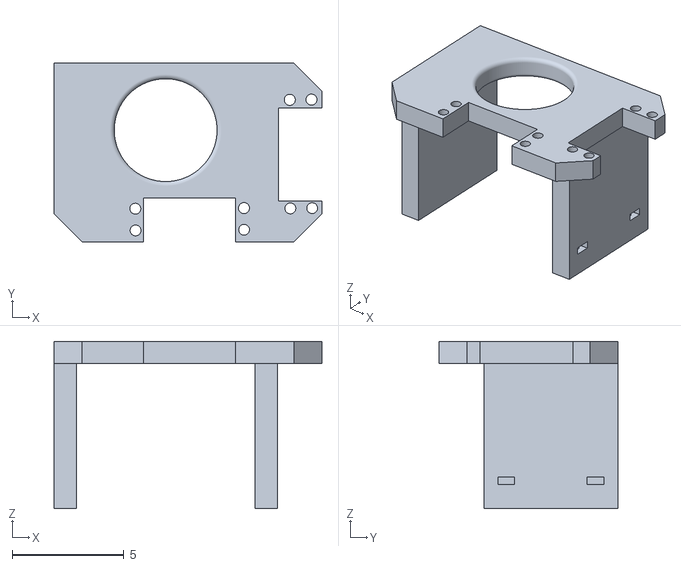
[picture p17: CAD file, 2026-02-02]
hardware/3d_models/ServoControl_Joystick/Support_servo_joystick.stl
12.0 x 8.00 x 7.50

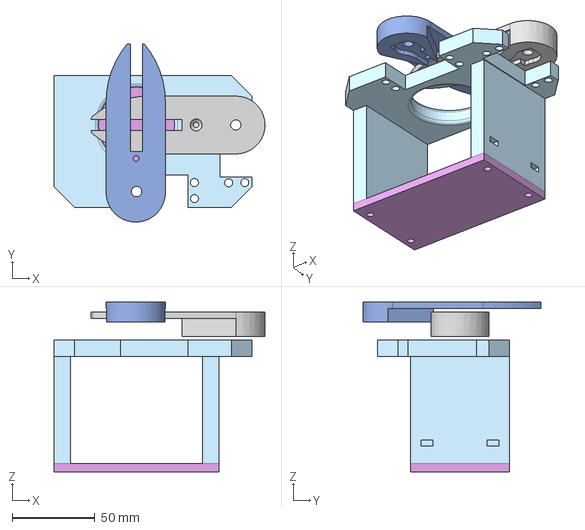
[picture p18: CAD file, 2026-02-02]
hardware/3d_models/ServoControl_Joystick/Servo_controller_Joystick.iges
127.9 x 108.0 x 103.0 mm

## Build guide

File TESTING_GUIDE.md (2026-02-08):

# Guide de Test Complet - E-WheelChAIr

## 🎯 Objectif

Ce guide vous accompagne pas à pas pour tester l'intégration complète du système avec **1 Arduino Mega** gérant :
- Joystick PS2 (lecture)
- Servos MG996R (contrôle)
- Capteurs ultrasons (à venir)
- Interface vision (à venir)

## 📋 Prérequis

### 1. Matériel Nécessaire

| Composant | Quantité | Branchement |
|---|---|---|
| Arduino Mega 2560 | 1 | USB → Raspberry Pi |
| Joystick PS2 | 1 | A0 (X), A1 (Y), D2 (Button) |
| Servo MG996R | 2 | D9 (Y-axis), D10 (X-axis) |
| Alimentation 6V | 1 | Pour les servos |
| Câbles Dupont | 10+ | Connexions diverses |
| Raspberry Pi 4 | 1 | ROS2 + USB |

### 2. Logiciels Installés

- ROS2 Humble
- IDE Arduino 2.x
- Bibliothèques Arduino standard (Servo.h)
- Dépendances Python (pyserial, pyyaml)
- Dépendances vision (OpenCV, etc.)

## 🔧 Préparation

### 1. Branchements Électroniques

```
[Joystick PS2]
   ├── A0 → Arduino A0 (X-axis)
   ├── A1 → Arduino A1 (Y-axis)
   └── D2 → Arduino D2 (Button - optionnel)

[Arduino Mega]
   ├── D9  → Servo Y-axis (Avant/Arrière)
   ├── D10 → Servo X-axis (Gauche/Droite)
   ├── GND → GND commune
   └── 5V  → Alimentation servos (via régulateur)

[Servos MG996R]
   ├── Rouge  → +6V (alimentation externe)
   ├── Marron → GND
   └── Orange → Signal (D9 ou D10)

[Arduino Mega] → [USB] → [Raspberry Pi]
```

### 2. Téléchargement du Code Arduino

1. Ouvrir `hardware/arduino/ewheelchair_controller/ewheelchair_controller.ino` dans l'IDE Arduino
2. Sélectionner : `Outils > Carte > Arduino Mega or Mega 2560`
3. Sélectionner le port USB (ex: `/dev/ttyACM0`)
4. Télécharger (Upload) - ✅

### 3. Compilation ROS2

```bash
cd ~/E-WheelChAIr
colcon build --symlink-install
source install/setup.bash
```

## 🧪 Tests par Étapes

### Étape 1 : Test des Servos (Sans Joystick)

**Objectif** : Vérifier que les servos répondent correctement.

**Méthode** :
```bash
# Lancer le node arduino_bridge
ros2 run arduino_bridge arduino_bridge_node

# Envoyer une commande manuelle
ros2 topic pub /servo_commands custom_msgs/msg/ServoCommand "{x_normalized: 0.0, y_normalized: 0.0}"
```

**Résultats attendus** :
- Servos se positionnent à la position neutre (X=85°, Y=92°)
- Message de confirmation dans le terminal : `SERVO_OK:X=85,Y=92°`

**Tester les amplitudes** :
```bash
# Avant/Droite (X=+15°, Y=+15°)
ros2 topic pub /servo_commands custom_msgs/msg/ServoCommand "{x_normalized: 1.0, y_normalized: 1.0}"

# Arrière/Gauche (X=-15°, Y=-15°)
ros2 topic pub /servo_commands custom_msgs/msg/ServoCommand "{x_normalized: -1.0, y_normalized: -1.0}"
```

### Étape 2 : Test du Joystick (Sans ROS)

**Objectif** : Vérifier que le joystick est correctement lu.

**Méthode** :
1. Ouvrir le moniteur série Arduino (115200 bauds)
2. Bouger le joystick dans toutes les directions

**Résultats attendus** :
- Messages `JOYSTICK,X,Y` affichés en continu
- X et Y varient entre 75 et 105 (90±15)
- Retour à 90,85 au centre

### Étape 3 : Test Intégré (Joystick + Servos)

**Objectif** : Vérifier le système complet en mode local.

**Méthode** :
1. Déconnecter le Raspberry Pi
2. Alimenter l'Arduino
3. Bouger le joystick

**Résultats attendus** :
- Servos suivent exactement les mouvements du joystick
- Amplitude limitée à ±15° (sécurité)
- Retour à position neutre si joystick relâché

### Étape 4 : Test ROS2 Complet

**Objectif** : Vérifier l'intégration ROS2.

**Méthode** :
```bash
# Lancer le système complet
ros2 launch e_wheelchair_launch ewheelchair_all.launch.py

# Monitorer les topics
ros2 topic echo /joystick_data
ros2 topic echo /servo_commands
ros2 topic echo /vision_data
```

**Résultats attendus** :
1. `/joystick_data` : Messages continus avec x,y entre -1.0 et 1.0
2. `/servo_commands` : Commandes servos avec angles correspondants
3. Servos répondent en temps réel aux mouvements du joystick
4. `/vision_data` : Messages de vision si activé

### Étape 5 : Test de Sécurité

**Objectif** : Vérifier les mécanismes de sécurité.

**Tests** :
1. **Déconnexion USB** : Servos doivent retourner à position neutre
2. **Valeurs hors limite** : Doivent être clampées à ±15°
3. **Timeout** : Après 1s sans commande, retour à neutre

**Commande de test** :
```bash
# Essayer de dépasser les limites (doit être clampé)
ros2 topic pub /servo_commands custom_msgs/msg/ServoCommand "{x_normalized: 2.0, y_normalized: 2.0}"
```

## 📊 Tableau de Validation

| Test | Résultat Attendu | ✅ Validé |
|---|---|---|
| Servos neutres | X=85°, Y=92° | ⬜ |
| Amplitude max | ±15° strict | ⬜ |
| Lecture joystick | 75-105 range | ⬜ |
| Communication USB | 115200 bauds | ⬜ |
| Intégration ROS2 | Topics actifs | ⬜ |
| Sécurité timeout | Retour neutre | ⬜ |
| Clamping | Pas de dépassement | ⬜ |

## 🐛 Dépannage

### Problème : Servos ne bougent pas

**Causes possibles** :
- Alimentation insuffisante (servos nécessitent 6V)
- Branchements incorrects
- Port USB non détecté
- Conflit avec le système de vision

**Solutions** :
```bash
# Vérifier le port USB
ls /dev/ttyACM*

# Vérifier les permissions
sudo chmod a+rw /dev/ttyACM0

# Tester avec un exemple Arduino simple

# Vérifier les topics de vision
ros2 topic list | grep vision
```

### Problème : Joystick non détecté

**Causes possibles** :
- Branchements A0/A1 incorrects
- Joystick défectueux
- Alimentation manquante

**Solutions** :
- Vérifier la continuité avec un multimètre
- Tester avec un autre joystick
- Vérifier 5V sur l'Arduino

### Problème : Communication ROS2 échoue

**Causes possibles** :
- Port série incorrect dans la config
- Node ROS2 non lancé
- Conflit de ports
- Problème de configuration vision

**Solutions** :
```bash
# Vérifier la configuration
cat src/arduino_bridge/config/arduino_config.yaml

# Lister les nodes actifs
ros2 node list

# Redémarrer le node
ros2 run arduino_bridge arduino_bridge_node

# Vérifier la configuration vision
cat src/pc_vision_bridge/config/vision_config.yaml
```

## 📈 Calibration

### 1. Calibration du Joystick

**Méthode** :
1. Lancer le moniteur série
2. Noter les valeurs min/max pour X et Y
3. Ajuster dans le code Arduino si nécessaire

**Valeurs typiques** :
- Centre : X=512, Y=512
- Min : X=0-100, Y=0-100
- Max : X=900-1023, Y=900-1023

### 2. Calibration des Servos

**Méthode** :
1. Positionner les servos manuellement
2. Ajuster les vis de fixation
3. Vérifier l'amplitude mécanique (±15°)
4. Vérifier l'intégration avec le système de vision

**Outils** :
```bash
# Commande de calibration
ros2 topic pub /servo_commands custom_msgs/msg/ServoCommand "{x_normalized: 0.5, y_normalized: 0.0}"

# Vérifier les données de vision
ros2 topic echo /vision_data
```

## ✅ Checklist avant Déploiement

- [ ] Branchements vérifiés (2x)
- [ ] Alimentation stable (6V pour servos)
- [ ] Code Arduino téléversé
- [ ] ROS2 compilé et sourcé
- [ ] Ports série configurés
- [ ] Tests unitaires passés
- [ ] Sécurité mécanique vérifiée
- [ ] Interrupteur d'urgence accessible
- [ ] Système de vision configuré

## 📚 Documentation Complémentaire

- [Bibliothèque Servo Arduino](https://www.arduino.cc/en/Reference/Servo)
- [ROS2 Troubleshooting](https://docs.ros.org/en/humble/Troubleshooting.html)
- [Guide de Sécurité Électrique](https://learn.sparkfun.com/tutorials/electrical-safety)
- [OpenCV Documentation](https://docs.opencv.org/)

---

**Note** : Toujours tester les mouvements des servos **avant** de connecter au joystick du fauteuil.
**Sécurité** : Un adulte doit superviser les tests initiaux.
**Support** : Pour assistance, consulter le README principal ou ouvrir une issue GitHub.

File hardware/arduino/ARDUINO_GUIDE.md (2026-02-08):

# 📖 E-WheelChAIr Arduino Controller - Complete Guide

## 🎯 Overview

This guide explains the **E-WheelChAIr Arduino Controller** - the hardware interface that connects user input, sensors, and actuators to the ROS2 system.

## 🔧 Hardware Components

### Required Hardware
- **Arduino Mega 2560** (required for sufficient I/O pins)
- **PS2 Joystick** (analog thumbstick for user control)
- **2x MG996R Servo Motors** (for wheelchair joystick manipulation)
- **3x HC-SR04 Ultrasonic Sensors** (for obstacle detection)

### Why Arduino Mega?
- **More I/O pins** than Uno/Nano
- **Multiple serial ports** for future expansion
- **Better performance** for real-time control
- **More memory** for complex logic

## 📊 Pin Mapping (Critical!)

### Analog Inputs (Joystick)
```
A0 → Joystick X-axis (Left/Right)
A1 → Joystick Y-axis (Forward/Backward)
```

### Digital I/O (Servos)
```
D9  → Servo Y (Vertical - Forward/Backward)
D10 → Servo X (Horizontal - Left/Right)
```

### Digital I/O (Ultrasonic Sensors)
```
Rear Right Sensor (US1):
  30 → Trigger
  31 → Echo

Rear Central Sensor (US2):
  32 → Trigger  
  33 → Echo

Rear Left Sensor (US3):
  34 → Trigger
  35 → Echo
```

### Power Connections
```
5V  → Joystick + Ultrasonic sensors + Servo
GND → Common ground for ALL components
```

## ⚙️ Servo Configuration (Most Important!)

### Neutral Positions
- **Servo X (Horizontal)**: 85° (NOT 90°!)
- **Servo Y (Vertical)**: 92° (NOT 90°!)

### Movement Range
- **Amplitude**: ±15° from neutral
- **Servo X**: 70° to 100° (85° ± 15°)
- **Servo Y**: 77° to 107° (92° ± 15°)

### Why 85° for X-axis?
The X-axis neutral is **85° instead of 90°** because:
- Matches the physical mechanics of the wheelchair joystick
- Provides better centering for the wheelchair control
- Optimized through testing and calibration

### Why 92° for Y-axis?
The X-axis neutral is **92° instead of 90°** because:
- Matches the physical mechanics of the wheelchair joystick
- Provides better centering for the wheelchair control
- Optimized through testing and calibration

## 🔄 Serial Communication Protocol

### Connection
```
Arduino Mega (USB) → Raspberry Pi (/dev/ttyACM0)
Baud Rate: 115200
Data Format: ASCII text commands
```

### Command Format
All commands end with newline (`\n`) character.

#### ROS2 → Arduino Commands

1. **SERVO,X,Y** - Set servo positions
   ```
   SERVO,85,92
   ```
   - `X`: X-axis angle (70-100°)
   - `Y`: Y-axis angle (77-107°)
   - Response: `SERVO_OK,X,Y`

2. **NEUTRAL** - Return to neutral position
   ```
   NEUTRAL
   ```
   - Response: `NEUTRAL_OK`

3. **STATUS** - Request current status
   ```
   STATUS
   ```
   - Response: `STATUS,currentX,currentY,neutralX,neutralY,amplitude`

#### Arduino → ROS2 Data

1. **JOYSTICK,X,Y** - Joystick position (20Hz)
   ```
   JOYSTICK,95,88
   ```
   - `X`: X-axis angle (0-180°)
   - `Y`: Y-axis angle (0-180°)

2. **ULTRASONIC,d1,d2,d3** - Sensor distances (20Hz)
   ```
   ULTRASONIC,0.50,1.20,0.85,0.60
   ```
   - `d1`: Rear Right distance (meters)
   - `d2`: Rear Central distance (meters)
   - `d3`: Rear Left distance (meters)

3. **ERROR,message** - Error messages
   ```
   ERROR: Unknown command: INVALID
   ```

## ⚠️ Safety Features

### 1. Amplitude Limiting
```cpp
// Strict ±15° limit enforced
xAngle = constrain(xAngle, neutralX - amplitude, neutralX + amplitude);
yAngle = constrain(yAngle, neutralY - amplitude, neutralY + amplitude);
```

### 2. Timeout Protection
```cpp
// If no commands for 1 second, return to neutral
if (millis() - lastCommandTime > TIMEOUT_MS) {
  moveToNeutral();
}
```

### 3. Distance Clamping
```cpp
// Ultrasonic readings constrained to reasonable range
if (distance < 2.0) distance = 2.0;      // Minimum 2cm
if (distance > 400.0) distance = 400.0;  // Maximum 4m
```

### 4. Emergency Stop
```cpp
// Immediate return to neutral position
emergencyStop();
```

## 📈 Data Flow

```
User Input → Joystick → Arduino → ROS2 → AI Processing → Arduino → Servos → Wheelchair
                          ↑
                   Ultrasonic Data
                          ↑                    
                   Obstacle Detection
```

### Update Rates
- **Joystick Data**: 20Hz (every 50ms)
- **Ultrasonic Data**: 20Hz (every 50ms)
- **Servo Commands**: On-demand + timeout
- **Status Updates**: On-demand

## 🧪 Testing Procedure

### 1. Basic Functionality Test
```bash
python3 test_arduino.py
```

### 2. Manual Testing Steps

**Joystick Test:**
1. Move joystick in all directions
2. Verify serial output shows changing values
3. Check range: 0-180° for both axes

**Servo Test:**
1. Send: `SERVO,92,85` (neutral)
2. Send: `SERVO,107,95` (+15°)
3. Send: `SERVO,77,75` (-15°)
4. Verify physical movement matches commands

**Ultrasonic Test:**
1. Place hand 20cm from each sensor
2. Verify distance readings: ~0.20m
3. Test maximum range (4m)
4. Test minimum range (2cm)

**Safety Test:**
1. Send valid command
2. Disconnect serial for 2 seconds
3. Verify servos return to neutral
4. Check serial output: "TIMEOUT: Returned to neutral position"

## 🔌 Wiring Checklist

- [ ] Arduino Mega connected via USB to Raspberry Pi
- [ ] Joystick connected to A0, A1, +5V, GND
- [ ] Servo X connected to D10, +5V, GND
- [ ] Servo Y connected to D9, +5V, GND
- [ ] All ultrasonic sensors connected with correct Trig/Echo pins
- [ ] All components share common GND
- [ ] 5V power from Arduino to joystick and sensors

## ⚡ Power Requirements

### Arduino Mega
- **Power Source**: USB from Raspberry Pi
- **Current**: ~50mA (without servos)

### Servo Motors (MG996R)
- **Voltage**: 5V
- **Current**: Up to 2A per servo under load
- **Total**: 4A power supply recommended

### Sensors
- **Joystick**: 5V, <10mA
- **Ultrasonic (each)**: 5V, 15mA
- **Total sensors**: ~70mA

## 📊 Troubleshooting Guide

### Problem: Servos Don't Move
**Causes:**
- No external 6V power
- Incorrect wiring
- Servo power supply insufficient
- GND not common

**Solutions:**
1. Verify 5V connection
2. Check servo signal wires (D9, D10)
3. Test with simple Arduino servo example
4. Measure voltage at servo connectors

### Problem: Ultrasonic Always Shows 4.0m
**Causes:**
- Trig/Echo wires reversed
- No 5V power to sensor
- Sensor out of range (>4m)
- Object too close (<2cm)

**Solutions:**
1. Verify Trig→Trig, Echo→Echo wiring
2. Check 5V power connection
3. Test with hand at 20cm distance
4. Use serial monitor to debug

### Problem: No Serial Communication
**Causes:**
- Wrong baud rate
- Wrong port selected
- Arduino Serial Monitor open
- USB cable not connected

**Solutions:**
1. Verify baud rate is 115200
2. Check port with `ls /dev/ttyACM*`
3. Close Arduino Serial Monitor
4. Try different USB cable

### Problem: Joystick Not Responding
**Causes:**
- No 5V power to joystick
- A0/A1 not connected
- Joystick defective
- Analog pins damaged

**Solutions:**
1. Verify 5V and GND connections
2. Check A0/A1 wiring
3. Test with Arduino analog read example
4. Try different joystick

## 🎓 Key Concepts

### Servo Control
- **PWM Signals**: Servos use pulse-width modulation
- **50Hz Frequency**: Standard servo update rate
- **1-2ms Pulse**: Controls servo position
- **Neutral Position**: Critical for wheelchair safety

### Ultrasonic Sensing
- **Ping-Pong Principle**: Send pulse, measure echo time
- **Speed of Sound**: 340 m/s at sea level
- **Timeout**: Prevents infinite waiting
- **Interference**: Avoid reading multiple sensors simultaneously

### Serial Communication
- **Asynchronous**: No clock signal needed
- **Baud Rate**: Must match between devices
- **Protocol**: Simple text commands
- **Buffering**: Important for reliable communication

## 📚 Reference Information

### Servo Specifications (MZ996R)
- **Operating Voltage**: 4.8V - 7.2V
- **Torque**: 9.4kg·cm (4.8V), 11kg·cm
- **Speed**: 0.17sec/60° (4.8V), 0.14sec/60°
- **Weight**: 55g
- **Dimensions**: 40.7×19.7×42.9mm

### Ultrasonic Specifications (HC-SR04)
- **Operating Voltage**: 5V DC
- **Current**: 15mA
- **Range**: 2cm - 400cm
- **Accuracy**: 3mm
- **Angle**: 15° cone
- **Trigger Pulse**: 10μs TTL

### Arduino Mega Specifications
- **Microcontroller**: ATmega2560
- **Operating Voltage**: 5V
- **Input Voltage**: 7-12V (recommended)
- **Digital I/O Pins**: 54 (15 PWM)
- **Analog Input Pins**: 16
- **Flash Memory**: 256KB
- **SRAM**: 8KB
- **EEPROM**: 4KB
- **Clock Speed**: 16MHz

## 🔧 Maintenance Tips

### Regular Checks
1. **Servo Calibration**: Verify neutral positions weekly
2. **Ultrasonic Cleaning**: Clean sensor faces monthly
3. **Wiring Inspection**: Check connections for wear
4. **Power Supply Test**: Verify voltage levels

### Servo Care
- Avoid mechanical overload
- Don't force servos beyond limits
- Lubricate gears if noisy
- Check mounting screws regularly

### Sensor Care
- Keep ultrasonic sensors clean
- Avoid direct sunlight on sensors
- Check for physical damage
- Test range periodically

## 📖 Glossary

- **PWM**: Pulse-Width Modulation (servo control method)
- **Baud Rate**: Serial communication speed (bits per second)
- **Amplitude**: Maximum deviation from neutral position
- **Timeout**: Safety feature for lost communication
- **Echo**: Reflected ultrasonic pulse
- **Trig**: Trigger pulse for ultrasonic sensor
- **GND**: Ground (common reference voltage)

## 🎯 Quick Reference

### Common Commands
```bash
# Test serial connection
screen /dev/ttyACM1 115200

# Send neutral command
echo "NEUTRAL" > /dev/ttyACM1

# Request status
echo "STATUS" > /dev/ttyACM1

# Test servos
echo "SERVO,92,85" > /dev/ttyACM1
```

### Expected Responses
```
SERVO_OK,92,85        # Servo command confirmation
NEUTRAL_OK            # Neutral position confirmation
STATUS,85,92,85,92,15 # Current status
JOYSTICK,95,88        # Joystick position
ULTRASONIC,0.5,1.2,0.8,0.6 # Sensor distances
```

## 🚀 Integration with ROS2

The Arduino controller works with these ROS2 nodes:

### servo_controller_node
- **Receives**: Joystick data, ultrasonic data
- **Sends**: Servo commands
- **Topic**: `/servo_commands`
- **Rate**: 20Hz

### master_node
- **Receives**: All sensor data
- **Sends**: High-level commands
- **Topic**: `/master_commands`
- **Rate**: 10Hz

### visualization_node
- **Receives**: Sensor data
- **Displays**: Real-time plots
- **Topic**: `/sensor_data`
- **Rate**: 5Hz

## 📊 Performance Metrics

### System Latency
- **Joystick → Servo**: ~20ms
- **Ultrasonic → ROS2**: ~30ms
- **ROS2 → Servo**: ~15ms
- **Total Loop**: ~50ms (20Hz)

### Power Consumption
- **Idle**: ~100mA
- **Active**: ~500mA
- **Peak**: ~4.5A (servos moving)

### Communication Reliability
- **Baud Rate**: 115200 (11.5KB/s)
- **Data Rate**: ~500B/s
- **Utilization**: <5%
- **Error Rate**: <0.1%

## 🎓 Best Practices

1. **Always test servos before connecting to wheelchair**
2. **Use external power for servos** (never from Arduino!)
3. **Verify common ground** between all components
4. **Start with neutral position** on every power-up
5. **Monitor serial communication** during development
6. **Implement timeout protection** in all control loops
7. **Document all wiring** for future reference
8. **Test each component** individually before integration

## 📖 Conclusion

The E-WheelChAIr Arduino Controller is the **critical hardware interface** that enables safe, reliable communication between the user, sensors, and wheelchair. Understanding this component is essential for:

- **Troubleshooting** hardware issues
- **Calibrating** the system
- **Extending** functionality
- **Ensuring** user safety

Always refer to this guide when working with the Arduino controller, and don't hesitate to update it as the system evolves!

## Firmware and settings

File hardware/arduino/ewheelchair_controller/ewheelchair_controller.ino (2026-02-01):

/*****************************************************************
  E-WheelChAIr Arduino Controller (ROS Bridge CSV Version)
  
  Description :
  -------------
  - Contrôle 2 servos (X = gauche/droite, Y = avant/arrière)
  - Lit 3 capteurs ultrasons
  - Reçoit commandes ROS via USB (CSV)
  - Émet distances ultrasons et positions joystick sur USB
  - Fréquence fixe à 20 Hz
  - Gestion d’urgence (emergency stop)
  
  Auteur : E-WheelChAIr Team
  Date   : 2026
*****************************************************************/

#include <Servo.h>

// ============================
// Déclaration des servos
// ============================
Servo servoAvantArriere;  // Axe Y (avant/arrière)
Servo servoGaucheDroite;  // Axe X (gauche/droite)

// ============================
// Broches Arduino
// ============================
const int brocheVRx = A0;  // Joystick X
const int brocheVRy = A1;  // Joystick Y

const int brocheServoAvantArriere = 9;
const int brocheServoGaucheDroite = 10;

// Ultrasons (3 capteurs)
const int trigPin_one = 30;  
const int trigEcho_one = 31;

const int trigPin_two = 32;  
const int trigEcho_two = 33;

const int trigPin_thr = 34;  
const int trigEcho_thr = 35;

// ============================
// Paramètres servos
// ============================
const int angleNeutreAvantArriere = 92;
const int angleNeutreGaucheDroite = 87;

// ============================
// Gestion de la fréquence
// ============================
unsigned long lastLoopTime = 0;
const unsigned long LOOP_INTERVAL_MS = 50;

// ============================
// Servo state
// ============================
int servoX_angle = angleNeutreGaucheDroite;
int servoY_angle = angleNeutreAvantArriere;

// ============================
// WATCHDOG ROS
// ============================
unsigned long lastCommandTime = 0;
const unsigned long COMMAND_TIMEOUT_MS = 500;

// ============================
// Setup
// ============================
void setup() {
  Serial.begin(115200); // Flux série rapide

  // Config capteurs ultrasons
  pinMode(trigPin_one, OUTPUT); pinMode(trigEcho_one, INPUT);
  pinMode(trigPin_two, OUTPUT); pinMode(trigEcho_two, INPUT);
  pinMode(trigPin_thr, OUTPUT); pinMode(trigEcho_thr, INPUT);

  // Attache les servos
  servoAvantArriere.attach(brocheServoAvantArriere);
  servoGaucheDroite.attach(brocheServoGaucheDroite);

  // Position neutre
  servoAvantArriere.write(angleNeutreAvantArriere);
  servoGaucheDroite.write(angleNeutreGaucheDroite);

  Serial.println("READY"); // Message initial pour debug
}

// ============================
// Loop principal
// ============================
void loop() {
  unsigned long currentTime = millis();
  if (currentTime - lastLoopTime < LOOP_INTERVAL_MS) return;
  lastLoopTime = currentTime;

  // -----------------------------
  // Lecture ultrasons
  // -----------------------------
  int d1 = readUltrasonic(trigPin_one, trigEcho_one);
  int d2 = readUltrasonic(trigPin_two, trigEcho_two);
  int d3 = readUltrasonic(trigPin_thr, trigEcho_thr);

  // Envoi distances sur série (CSV)
  Serial.print("U,"); // Type U = Ultrasons
  Serial.print(d1); Serial.print(",");
  Serial.print(d2); Serial.print(",");
  Serial.println(d3);

  // -----------------------------
  // Lecture joystick
  // -----------------------------
  // ============================
  // Paramètres du joystick (à ajuster une seule fois)
  // ============================
  const int JOY_NEUTRE_X = 510;  // Valeur mesurée au repos (ex: 510)
  const int JOY_NEUTRE_Y = 515;  // Valeur mesurée au repos (ex: 515)
  const int JOY_AMPLITUDE = 300; // Amplitude autour du neutre (ex: ±250)

  // Lecture joystick
  int valeurX = analogRead(brocheVRx);
  int valeurY = analogRead(brocheVRy);

  // Normalisation CENTRÉE SUR LE NEUTRE RÉEL
  float normX = (valeurX - JOY_NEUTRE_X) / (float)JOY_AMPLITUDE;  // [-1.0, 1.0]
  float normY = (valeurY - JOY_NEUTRE_Y) / (float)JOY_AMPLITUDE;  // [-1.0, 1.0]

  // Contraintes (inchangées)
  normX = constrain(normX, -1.0, 1.0);
  normY = constrain(normY, -1.0, 1.0);

  // ===== ZONE MORTE =====
  const float DEADZONE = 0.01;  // Seuil pour ignorer les micro-mouvements
  if (abs(normX) < DEADZONE) normX = 0.0;
  if (abs(normY) < DEADZONE) normY = 0.0;
  // ======================

  // Limite au cas où le joystick sortirait légèrement de la plage
  //if (normX > 1.0) normX = 1.0;
  //if (normX < -1.0) normX = -1.0;
  //if (normY > 1.0) normY = 1.0;
  //if (normY < -1.0) normY = -1.0;
  Serial.print("J,");
  Serial.print(normX, 6); Serial.print(",");
  Serial.println(normY, 6);

  // ============================
  // Lire commandes ROS AVANT servo
  // ============================
  handleIncomingSerial();

  // ============================
  // WATCHDOG : retour neutre si ROS muet
  // ============================
  if (millis() - lastCommandTime > COMMAND_TIMEOUT_MS) {
  servoX_angle = angleNeutreGaucheDroite;
  servoY_angle = angleNeutreAvantArriere;
  }

  // ============================
  // Appliquer des commandes servo depuis ROS
  // ============================
  servoGaucheDroite.write(servoX_angle);
  servoAvantArriere.write(servoY_angle);
  Serial.print("Servo X angle: ");
  Serial.print(servoX_angle);
  Serial.print(" | Servo Y angle: ");
  Serial.println(servoY_angle);
}

// ============================
// Lecture ultrasons
// ============================
int readUltrasonic(int trigPin, int echoPin) {
  digitalWrite(trigPin, LOW);
  delayMicroseconds(5);
  digitalWrite(trigPin, HIGH);
  delayMicroseconds(10);
  digitalWrite(trigPin, LOW);

  long duree = pulseIn(echoPin, HIGH, 30000); // Timeout 30ms
  if (duree == 0) return 400; // Si pas de mesure

  return duree * 0.034 / 2; // Conversion cm
}

  // ============================
  // Lecture commandes ROS
  // ============================
  void handleIncomingSerial() {
    while (Serial.available()) {
      String line = Serial.readStringUntil('\n');
      line.trim();

      if (line.length() == 0) continue;

      // DEBUG
      Serial.print("RX RAW: ");
      Serial.println(line);

      // Format attendu: S,x,y,emergency
      if (!line.startsWith("S,")) return;

      int firstComma = line.indexOf(',');
      int secondComma = line.indexOf(',', firstComma + 1);
      int thirdComma = line.indexOf(',', secondComma + 1);

      if (firstComma < 0 || secondComma < 0) return;

      String sx = line.substring(firstComma + 1, secondComma);
      String sy = (thirdComma > 0) 
                    ? line.substring(secondComma + 1, thirdComma)
                    : line.substring(secondComma + 1);

      sx.trim();
      sy.trim();

      int newX = sx.toInt();
      int newY = sy.toInt();

      Serial.print("Parsed X=");
      Serial.print(newX);
      Serial.print(" Y=");
      Serial.println(newY);

      // Accepter plage servo large
      if (newX >= 0 && newX <= 180 && newY >= 0 && newY <= 180) {
        servoX_angle = newX;
        servoY_angle = newY;
        lastCommandTime = millis(); // 🟢 WATCHDOG RESET
        Serial.println("Servo CMD ACCEPTED");
      } else {
        Serial.println("Servo CMD REJECTED");
      }

      // Emergency
      if (thirdComma > 0) {
        String emergencyStr = line.substring(thirdComma + 1);
        emergencyStr.trim();
        bool emergency = emergencyStr.toInt() > 0;

        if (emergency) {
          servoX_angle = angleNeutreGaucheDroite;
          servoY_angle = angleNeutreAvantArriere;
          Serial.println("EMERGENCY STOP ACTIVE");
        }
      }
    }
  }

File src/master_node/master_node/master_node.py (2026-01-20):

import rclpy
import yaml
import os
from rclpy.node import Node

# Permet de retrouver le dossier share/ d’un package ROS
from ament_index_python.packages import get_package_share_directory

pkg_share = get_package_share_directory('master_node')

master_config_file = os.path.join(
    pkg_share, 'config', 'master_config.yaml'
)
servo_config_file = os.path.join(
    pkg_share, 'config', 'servo_config.yaml'
)

# Messages personnalisés du projet
from custom_msgs.msg import (
    EmergencyData, 
    ObstacleDetection,
    VisionObstacle,
    Joystick,
    UltrasonicArray,
    ServoCommand
)

# (Non utilisé actuellement, mais importé)
from geometry_msgs.msg import Twist
from std_msgs.msg import Float32MultiArray

class MasterNode(Node):
    """
    MASTER NODE
    ===========
    Nœud central du fauteuil roulant.
    Rôles :
    LOGIQUE DES PRIORITÉS :
    1. Emergency Stop → priorité absolue → bloque tous les mouvements
    2. Joystick actif → source principale du mouvement
    3. Front obstacle → modificateur pour l’avance
    4. Rear obstacle (ultrasons) → modificateur pour la marche arrière
    """


    def __init__(self):
        super().__init__('master_node')

        # =====================================================
        #                  PARAMÈTRES CONFIGURABLES
        # =====================================================
        # ===========================
        # Chargement des configs
        # ===========================
        with open(master_config_file, 'r') as f:
            master_cfg = yaml.safe_load(f)

        with open(servo_config_file, 'r') as f:
            servo_cfg = yaml.safe_load(f)

        # ===========================
        # Paramètres de sécurité
        # ===========================
        safety = master_cfg.get('safety', {})
        self.emergency_stop_timeout = safety.get('emergency_stop_timeout', 0.5)
        self.front_obstacle_caution_distance = safety.get('front_obstacle_caution_distance', 0.5)
        self.front_obstacle_stop_distance = safety.get('front_obstacle_stop_distance', 0.2)
        self.rear_obstacle_stop_distance = safety.get('rear_obstacle_stop_distance', 0.2)
        self.max_speed = safety.get('max_speed', 1.0)

        # ===========================
        # Paramètres servos
        # ===========================
        self.servo_neutral_x = servo_cfg['servo_x']['neutral']  # 85
        self.servo_neutral_y = servo_cfg['servo_y']['neutral']  # 90
        self.servo_min_x = servo_cfg['servo_x']['min']          # 70
        self.servo_max_x = servo_cfg['servo_x']['max']          # 100
        self.servo_min_y = servo_cfg['servo_y']['min']          # 75
        self.servo_max_y = servo_cfg['servo_y']['max']          # 105
        self.servo_amplitude = servo_cfg.get('amplitude', 15)  # 15


        # ===========================
        # Initialisation des états
        # ===========================
        self.joystick_x = 0.0
        self.joystick_y = 0.0
        self.front_obstacle_distance = 1.0
        self.rear_obstacle_distance = 1.0
        self.vision_obstacle = None
        self.emergency_stop = False

        # =====================================================
        #                    SUBSCRIBERS
        # =====================================================

        # Joystick venant de arduino_data_receiver
        # msg.data = [x, y] avec x,y ∈ [-1 ; 1]
        self.create_subscription(
            Joystick,
            '/joystick/data',
            self.joystick_callback,
            10
        )

        # Données ultrasons (tableau de distances en mètres)
        self.create_subscription(
            UltrasonicArray,
            '/ultrasonic/data',
            self.ultrasonic_callback,
            10
        )

        # Vision Semantique
        self.create_subscription(
            VisionObstacle,
            '/vision/obstacle',
            self.vision_obstacle_callback,
            10
        )

        # Détection d’obstacles par Camera profondeur
        self.create_subscription(
            ObstacleDetection,
            '/obstacle_detection',
            self.front_obstacle_callback,
            10
        )

        self.create_subscription(
            EmergencyData,
            '/emergency_data',
            self.emergency_callback,
            10)

        # ===========================
        # Log info
        # ===========================
        self.get_logger().info("Master Node initialized with YAML configs")

        # =====================================================
        #                    PUBLISHERS
        # =====================================================

        # Commande finale envoyée au servo_controller
        self.servo_command_pub = self.create_publisher(
            ServoCommand,
            '/servo_commands',
            10
        )

        self.get_logger().info("Master Node started")


    # =====================================================
    #                  CALLBACKS ENTRÉES
    # =====================================================
    def joystick_callback(self, msg: Joystick):
        """
        Réception du joystick Arduino.
        C'est l'intention brute de l'utilisateur.
        """
        # On vérifie que x et y existent
        if msg.x is None or msg.y is None:
            return

        self.joystick_x = float(msg.x)
        self.joystick_y = float(msg.y)

        # --- Debug log ---
        #self.get_logger().info(
        #    f"Joystick reçu: x={self.joystick_x:.3f}, y={self.joystick_y:.3f}"
        #)

        # À CHAQUE NOUVELLE INTENTION → on redécide
        self.decide_and_publish()

    def ultrasonic_callback(self, msg: UltrasonicArray):
        """Ultrasons arrière → marche arrière"""
        # Vérifie que la liste n'est pas vide
        if len(msg.distances) > 0:
            # Exemple : prendre la distance minimale pour obstacle arrière
            self.rear_obstacle_distance = min(msg.distances)
            # --- Debug log ---
            #self.get_logger().info(
            #    f"Rear obstacle distance: {self.rear_obstacle_distance:.2f} m"
            #)

    def front_obstacle_callback(self, msg: ObstacleDetection):
        """Depth camera frontale → avance"""
        self.front_obstacle_distance = msg.relative_distance

    def vision_obstacle_callback(self, msg: VisionObstacle):
        if msg.detection_confidence < 0.5:
            self.vision_obstacle = None
        else:
            self.vision_obstacle = msg
            self.front_obstacle_distance = msg.forward_offset

    def emergency_callback(self, msg: EmergencyData):
        """
        Arrêt d’urgence = priorité ABSOLUE.
        """
        self.emergency_stop = msg.stop

        if self.emergency_stop:
            self.get_logger().warn(" EMERGENCY STOP ACTIVATED")
            self.decide_and_publish()
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

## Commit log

2025-11-01 Nettoyage : déplacement des dossiers ROS dans EWheelChAIr_ws/ et ajout de 3d_models/
2025-11-01 Ajout du contenu de EWheelChAIr_ws/
2025-11-01 Ajout complet du projet E-WheelChAIr (ROS + 3D)
2025-11-03 Modufication of project sctructure
    [Joystick _for_wheelchair.iges, Joystick_wheelchair.step]
2025-11-11 Réorganisation complète du projet : nouvelle arborescence et fichiers mis à jour
    [thumbstick_all.iges]
2025-11-11 Initial commit: Structure du package image_processing avec fichiers de configuration et de lancement
2025-11-11 Initial commit: Add lidar package
2025-11-12 Correction des fichiers sabertooth_controller et résolution des erreurs de compilation
    [master_node.py]
2025-11-12 Correction des commandes pour cloner le depot
2025-11-19 Reorganisation complete du WS plus adaptées a ROS2
    [Joystick _for_wheelchair.iges, Joystick_wheelchair.step, thumbstick_all.iges]
2026-01-02 Reorganisation Complete du projet suite a impossibiltié d'utiliser le sabertooth controller
    [servo_config.yaml]
2026-01-02 Ajout script test Arduino pour joystick et servo via raspberry
2026-01-05 ajout fichier launch pour teleoperation via joystick et servo
2026-01-05 modif fichier launch pour teleoperation via joystick et servo
2026-01-14 Last Modification ROS2 architecture for E-WheelChAIr (master node, custom msgs, sensors, servo control)
    [Joystick _for_wheelchair.iges, Joystick_wheelchair.step, servo_config.yaml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]
2026-01-14 Last Modification ROS2 architecture for E-WheelChAIr (wide and depth porcessing)
2026-01-16 Package ROS2 arduino data receiver
2026-01-16 mise a jour des Markdown
2026-01-16 mise a jour et regroupeemnt des fichier launch.py pour plus de simplicité
2026-01-18 Package ServoControl ControlCommend.msg mise a jour
2026-01-18 Package arduino receover et launch files mis a jour
2026-01-18 Mise a jour sketch arduino
2026-01-18 arduino sketch
2026-01-18 Mise a jour communication bidirectionelle arduino raspberry
2026-01-18 Arduino bridge
2026-01-18 Arduino bridge et launch fukes
2026-01-19 sketch arduino
2026-01-19 arduino bridge update
2026-01-20 arduino sketch tania
2026-01-20 arduino sketch ewheelchair controller simlification with tania sketch
2026-01-20 arduino sketch ewheelchair controller simplification with tania sketch
2026-01-22 arduino sketch autocalibration arduino uno and mega
2026-01-22 add autocalibration joystick for arduino giga
2026-01-23 launch servo-joystick
2026-01-23 normalisation joystick dans arduino
2026-01-26 Correction ultrasons et servomoteur
    [servo_config.yaml]
2026-01-28 correction arduino sketch
2026-01-28 correction arduino sketch avec watvhdog pour securité
    [ewheelchair_controller.ino]
2026-02-02 Modelisation 3D iges
    [Joystick _for_wheelchair.iges, Joystick_wheelchair.step, Servo_controller_Joystick.iges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]
2026-02-02 Modelisations 3D all parts
    [BasePart.stl, Camera_module.iges, Fixation_BackRest.iges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]
2026-02-02 Adding Raspberry PI procedure
2026-02-08 update with wheelchair view

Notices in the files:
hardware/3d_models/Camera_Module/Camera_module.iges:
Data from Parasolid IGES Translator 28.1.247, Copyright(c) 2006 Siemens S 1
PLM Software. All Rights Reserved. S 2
